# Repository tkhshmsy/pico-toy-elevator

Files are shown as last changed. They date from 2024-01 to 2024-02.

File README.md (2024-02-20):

# pico-toy-elevator

This is a toy that imitates the operation of Elevator.

My son loves Elevators, going up and down for hours, and watching YouTube about it every day.  
I hope he enjoys this...

## Features
* LCD displays floors and operations
* Pressed button is lights up
* Speak according to the movement of the elevator ( in Japanese ! )
* All parts are able to get from [Akizuki Denshi](https://akizukidenshi.com/catalog/default.aspx).
* Use Raspberry Pi Pico with Rust language.

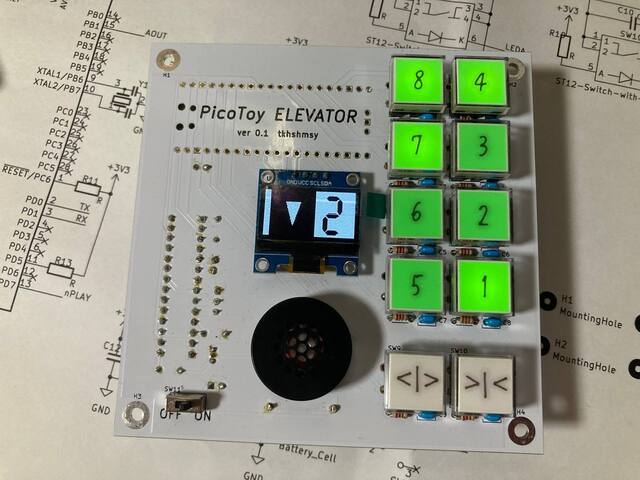
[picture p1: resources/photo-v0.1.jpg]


## Schematic and Layout

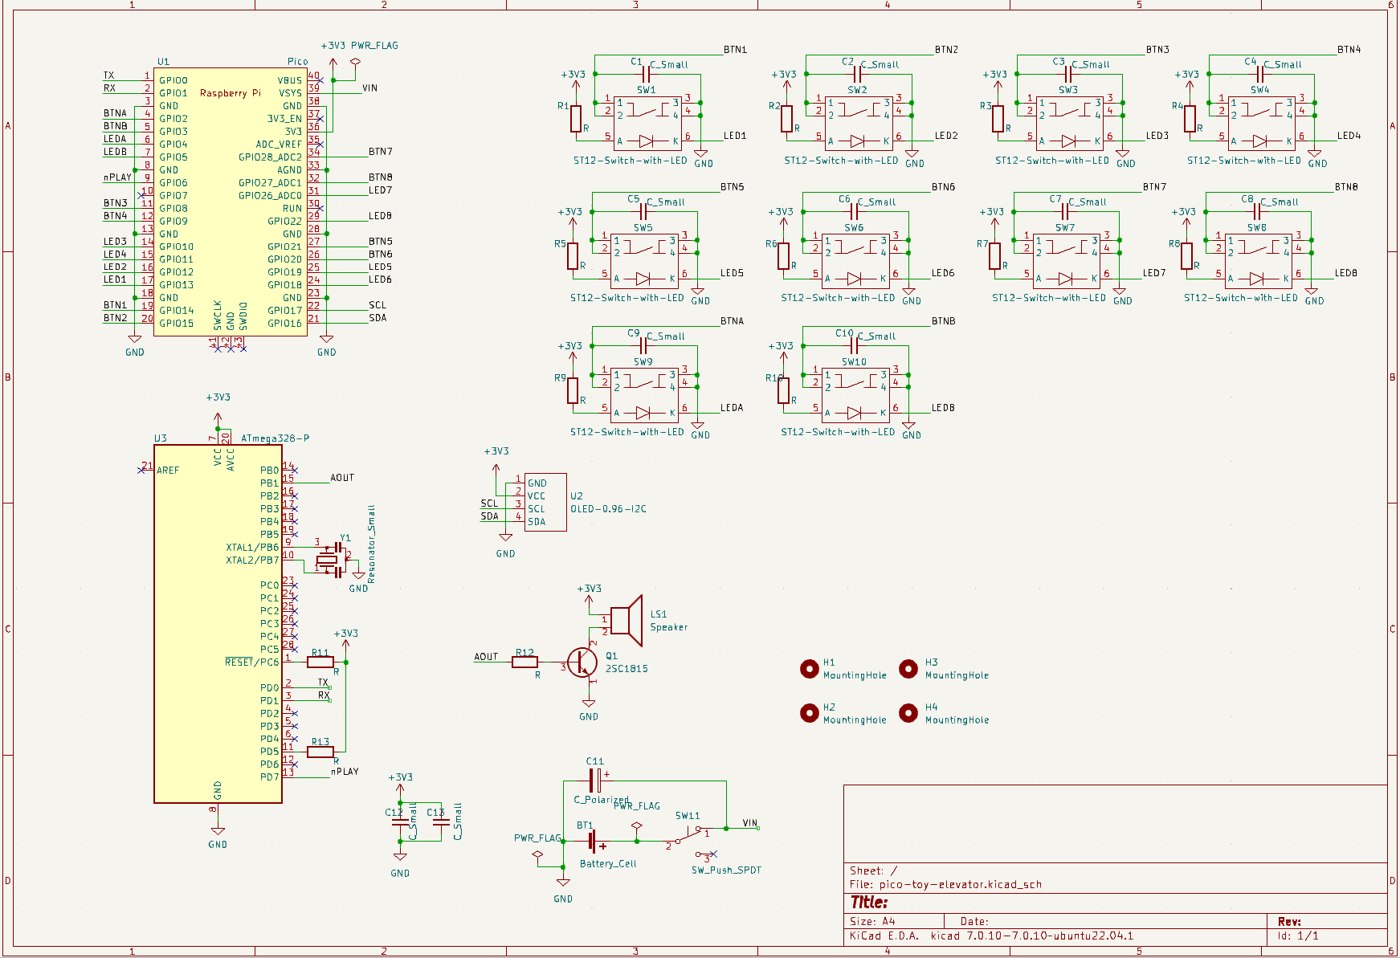
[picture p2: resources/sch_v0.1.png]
schmatic


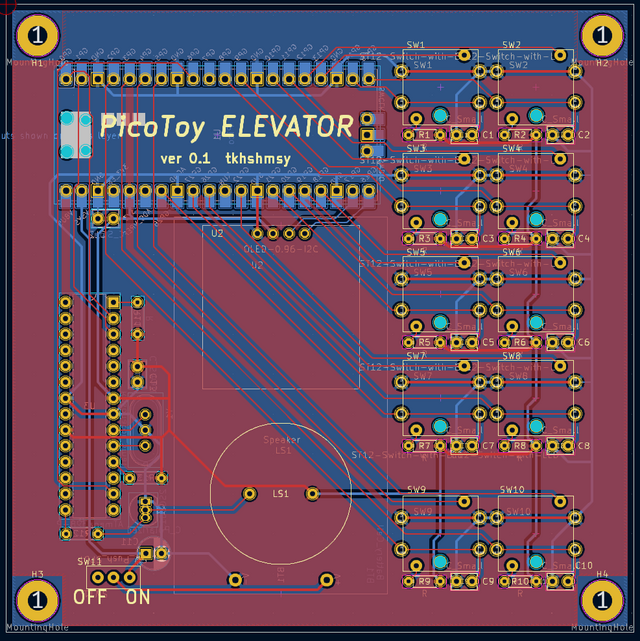
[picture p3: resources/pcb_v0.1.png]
layout


## Bill Of Materials
|Ref|Name|Qty|Description|Link|
|---|----|---|---|----|
|U1|RaspberryPi Pico|1|Micro Controller|[https://akizukidenshi.com/catalog/g/g116132/](https://akizukidenshi.com/catalog/g/g116132/) or [https://akizukidenshi.com/catalog/g/g118085/](https://akizukidenshi.com/catalog/g/g118085/)|
|U2|OLED|1|i2c, 0.96inch|[https://akizukidenshi.com/catalog/g/g112031/](https://akizukidenshi.com/catalog/g/g112031/)|
|U3|Aques Talk Pico|1|ATMega328P|[https://akizukidenshi.com/catalog/g/g109973/](https://akizukidenshi.com/catalog/g/g109973/)|
|BT1|Battery holder|1|2xAAA|[https://akizukidenshi.com/catalog/g/g110197/](https://akizukidenshi.com/catalog/g/g110197/)|
|C1,C2,C3,C4,C5,C6,C7,C8,C9,C10,C12,C13|Capacitor|12|0.1uF|[https://akizukidenshi.com/catalog/g/g115927/](https://akizukidenshi.com/catalog/g/g115927/)|
|C11|Capacitor polar|1|100uF|[https://akizukidenshi.com/catalog/g/g105002/](https://akizukidenshi.com/catalog/g/g105002/)|
|LS1|Speaker|1|8ohm 0.5W|[https://akizukidenshi.com/catalog/g/g109797/](https://akizukidenshi.com/catalog/g/g109797/)|
|Q1|2SC1815|1||[https://akizukidenshi.com/catalog/g/g106475/](https://akizukidenshi.com/catalog/g/g106475/)|
|R1,R2,R3,R4,R5,R6,R7,R8,R9,R10|Resistor 220|10|LED limit||
|R11,R13|Resistor 10K|2|Pull up||
|R12|Resistor 270|1|Speaker drive||
|SW1,SW2,SW3,SW4,SW5,SW6,SW7,SW8,SW9,SW10|Push Switch with LED|10|select any color|Green [https://akizukidenshi.com/catalog/g/g102009/](https://akizukidenshi.com/catalog/g/g102009/) Red [https://akizukidenshi.com/catalog/g/g102010](https://akizukidenshi.com/catalog/g/g102010) Yellow [https://akizukidenshi.com/catalog/g/g115372](https://akizukidenshi.com/catalog/g/g115372)|
|SW11|Slide Switch|1|Power SW|[https://akizukidenshi.com/catalog/g/g115707/](https://akizukidenshi.com/catalog/g/g115707/)|
|Y1|Resonator|1|16MHz|[https://akizukidenshi.com/catalog/g/g109576/](https://akizukidenshi.com/catalog/g/g109576/)|

## License
* MIT

## Author
* tkhshmsy@gmail.com

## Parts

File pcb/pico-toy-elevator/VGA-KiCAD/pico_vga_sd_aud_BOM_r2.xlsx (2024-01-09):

RPI-PVAS pico_vga_sd_aud BOM Rev2
17/079/2020
Reference designators | Quantity | Manufacturer Part Number (MPN) | Manufacturer | Description | Value
C1, C2 | 2 | GCM188R71C105KA64J | Murata | CAP CER 1UF 16V X7R 0603 | 1u
C9, C11 | 2 | GRM188R71A225KE15D | Murata | CAP CER 2.2UF 10V X7R 0603 | 2.2u
C3, C10, C16, C19 | 4 | GRM188R61A106KE69J | Murata | CAP CER 10UF 10V X5R 0603 | 10u
C4, C5, C6, C7, C8, C12, C13 | 7 | GRM155R71E104KE14J | Murata | CAP CER 0.1UF 25V X7R 0402 | 100n
C14, C15, C21 | 3 | GRM219R60J476ME44D | Murata | CAP CER 47UF 6.3V X5R 0805 | 47u
C17, C18 | 2 | GRM155R71H222KA01D | Murata | CAP CER 2200PF 50V X7R 0402 | 2.2n
D1 | 1 | MBR120VLSFT1G | ON Semiconductor | DIODE SCHOTTKY 20V 1A SOD123FL | MBR120VLSFT1G
J1, J2 | 2 | SJ-3523-SMT-TR | CUI Devices | CONN JACK STEREO 3.5MM SMD R/A | SJ-3523-SMT
J3 | 1 | 104031-0811 | Molex | CONN MICRO SD CARD PUSH-PULL R/A | 104031-0811
J4 | 1 | L77HDE15SD1CH4F | Amphenol ICC (Commercial Products) | CONN DSUB HD RCPT 15POS R/A SLDR | L77HDE15SD1CH4F
J5 | 1 | 10103594-0001LF | Amphenol ICC (FCI) | CONN RCPT USB2.0 MICRO B SMD R/A | 10103594-0001LF
J6 | 1 | TSW-102-23-T-S | Samtec Inc. | CONN HEADER VERT 2POS 2.54MM | TSW-102-23-T-S
J7 | 1 | 67997-208HLF | Amphenol ICC (FCI) | CONN HEADER VERT 8POS 2.54MM | 67997-208HLF
R1, R2 | 2 | RC0402FR-07220RL | Yageo | RES SMD 220 OHM 1% 1/16W 0402 | 220
R3, R4 | 2 | RC0402FR-07100RL | Yageo | RES SMD 100 OHM 1% 1/16W 0402 | 100
R5, R6 | 2 | RC0402FR-07470RP | Yageo | RES SMD 470 OHM 1% 1/16W 0402 | 470
R7, R8 | 2 | RC0402FR-071K8L | Yageo | RES SMD 1.8K OHM 1% 1/16W 0402 | 1.8K
R10, R11 | 2 | RC0402FR-0747RL | Yageo | RES SMD 47 OHM 1% 1/16W 0402 | 47
R20, R21, R22, R27, R32, R37 | 6 | RC0402FR-071KP | Yageo | RES SMD 1K OHM 1% 1/16W 0402 | 1k
R23, R24 | 2 | RC0402FR-0710KP | Yageo | RES SMD 10K OHM 1% 1/16W 0402 | 10k
R26, R31, R36 | 3 | RC0402FR-07499RL | Yageo | RES SMD 499 OHM 1% 1/16W 0402 | 499
R28, R33, R38 | 3 | RC0402FR-072KL | Yageo | RES SMD 2K OHM 1% 1/16W 0402 | 2k
R29, R34, R39 | 3 | RC0402FR-074K02L | Yageo | RES SMD 4.02K OHM 1% 1/16W 0402 | 4.02k
R30, R35, R40 | 3 | RC0402FR-078K06L | Yageo | RES SMD 8.06K OHM 1% 1/16W 0402 | 8.06k
SW1, SW2, SW3, SW4 | 4 | 434133025816 | Würth Elektronik | TACT SWITCH 4.2X3.2MM VERTICAL T | 434133025816
U1 | 1 | TLV70033DDCR | Texas Instruments | IC REG LINEAR 3.3V 200MA SOT23-5 | TLV70033DDCR
U3 | 1 | NC7WZ16P6X | ON Semiconductor | IC BUF NON-INVERT 5.5V SC70-6 | NC7WZ16P6X
U4 | 1 | PCM5101APWR | Texas Instruments | IC DAC 16/24/32BIT 384K 20TSSOP | PCM5101APWR

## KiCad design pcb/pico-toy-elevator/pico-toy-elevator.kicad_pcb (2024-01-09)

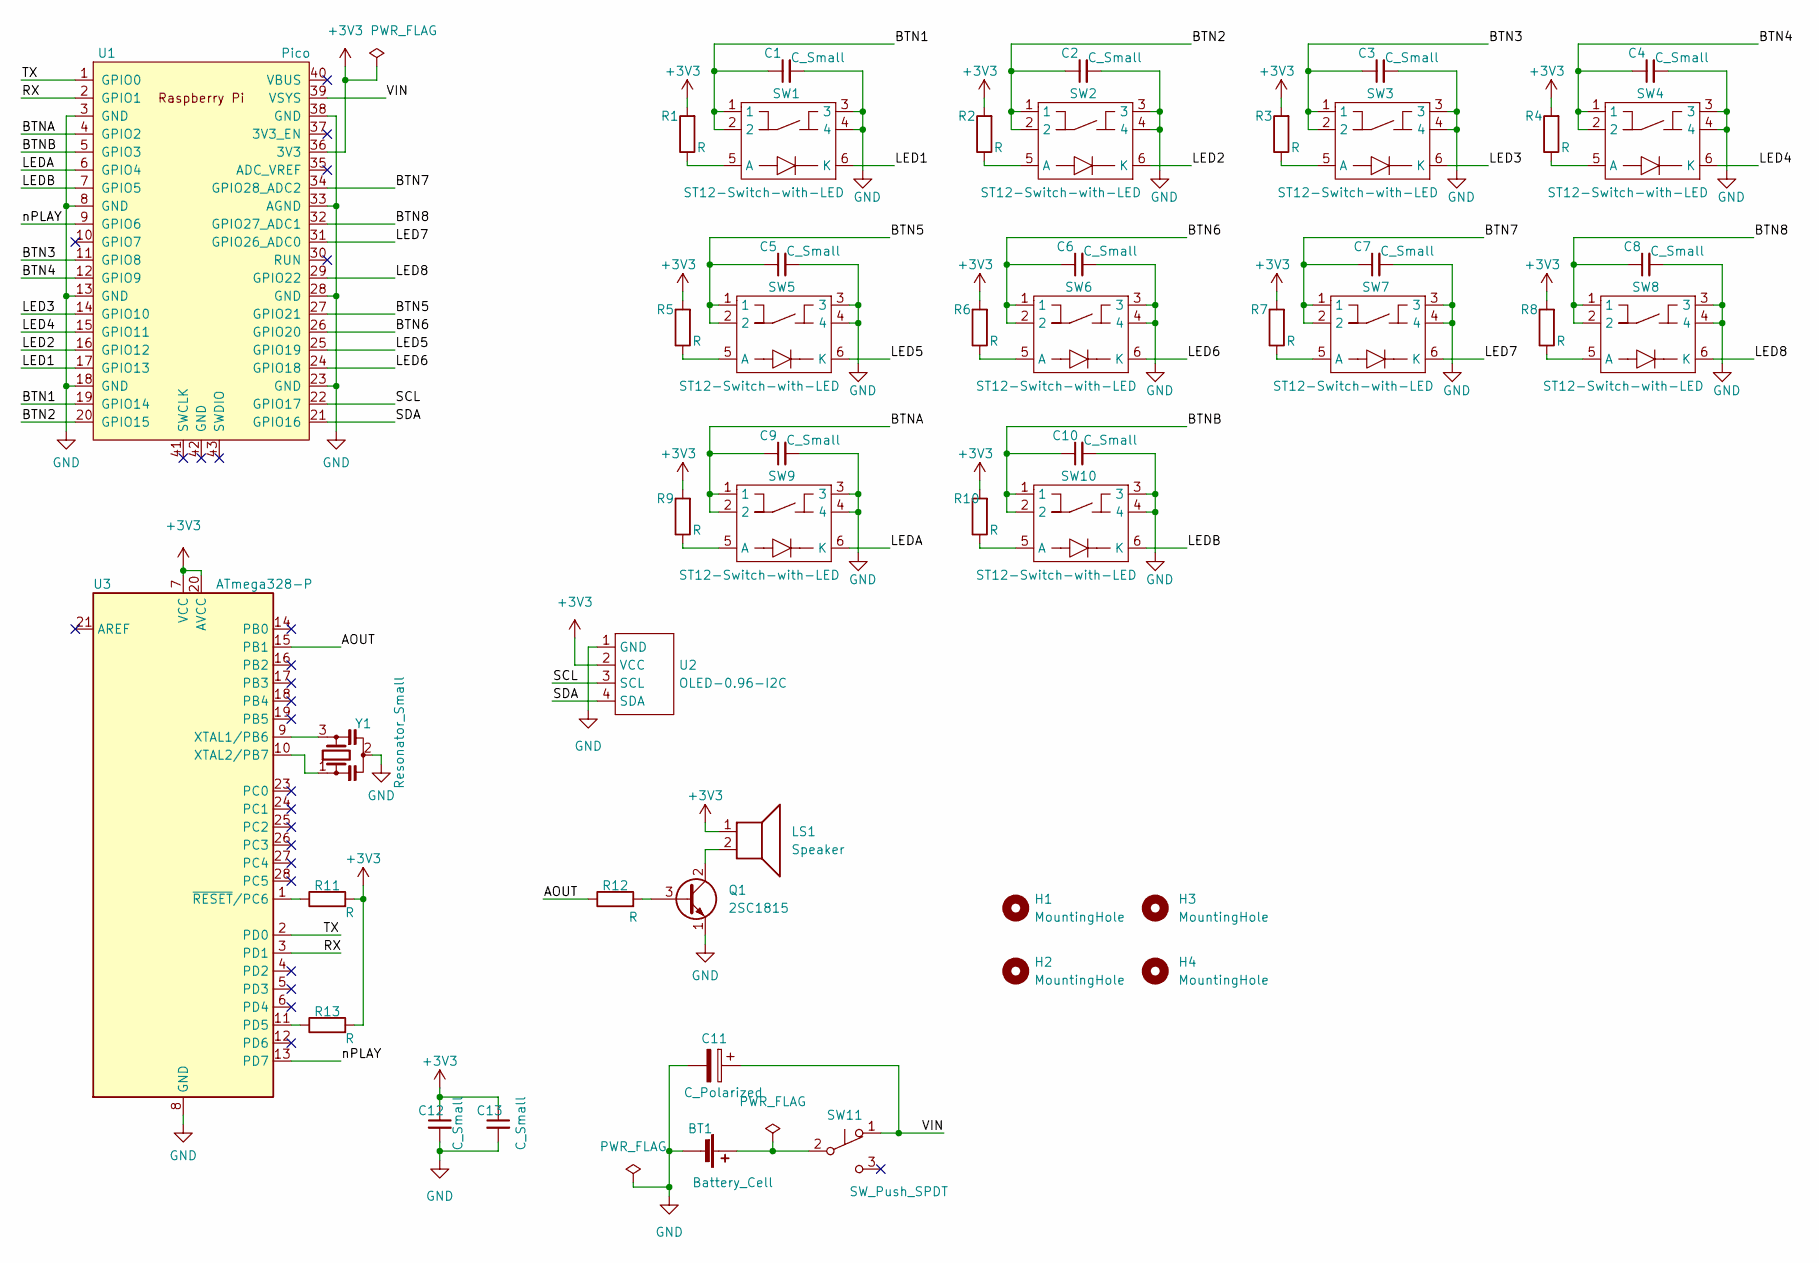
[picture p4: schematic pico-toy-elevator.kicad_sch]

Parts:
BT1: Battery_Cell; BH-321-2P24
C1, C2, C3, C4, C5, C6, C7, C8, C9, C10, C12, C13: C_Small; C_Rect_L4.0mm_W2.5mm_P2.50mm
C11: C_Polarized; CP_Radial_D5.0mm_P2.50mm
H1, H2, H3, H4: MountingHole; MountingHole_3.2mm_M3_Pad
LS1: Speaker; UGSM23A
Q1: 2SC1815; TO-92_Inline
R1, R2, R3, R4, R5, R6, R7, R8, R9, R10, R11, R12, R13: R; R_Axial_DIN0204_L3.6mm_D1.6mm_P5.08mm_Horizontal
SW1, SW2, SW3, SW4, SW5, SW6, SW7, SW8, SW9, SW10: ST12-Switch-with-LED; ST12
SW11: SW_Push_SPDT; SS-12D00G3
U1: Pico; RPi_Pico_SMD_TH
U2: OLED-0.96-I2C
U3: ATmega328-P; DIP-28_W7.62mm
Y1: Resonator_Small; Crystal_HC49-U-3Pin_Vertical

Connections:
+3V3: C12.1, C13.1, LS1.1, R1.2, R2.2, R3.2, R4.2, R5.2, R6.2, R7.2, R8.2, R9.2, R10.2, R11.2, R13.2, U1.36 (3V3), U2.2 (VCC), U3.7 (VCC), U3.20 (AVCC)
/AOUT: R12.1, U3.15 (PB1)
/BTN1: C1.1, SW1.1, SW1.2, U1.19 (GPIO14)
/BTN2: C2.1, SW2.1, SW2.2, U1.20 (GPIO15)
/BTN3: C3.1, SW3.1, SW3.2, U1.11 (GPIO8)
/BTN4: C4.1, SW4.1, SW4.2, U1.12 (GPIO9)
/BTN5: C5.1, SW5.1, SW5.2, U1.27 (GPIO21)
/BTN6: C6.1, SW6.1, SW6.2, U1.26 (GPIO20)
/BTN7: C7.1, SW7.1, SW7.2, U1.34 (GPIO28_ADC2)
/BTN8: C8.1, SW8.1, SW8.2, U1.32 (GPIO27_ADC1)
/BTNA: C9.1, SW9.1, SW9.2, U1.4 (GPIO2)
/BTNB: C10.1, SW10.1, SW10.2, U1.5 (GPIO3)
/LED1: SW1.6 (K), U1.17 (GPIO13)
/LED2: SW2.6 (K), U1.16 (GPIO12)
/LED3: SW3.6 (K), U1.14 (GPIO10)
/LED4: SW4.6 (K), U1.15 (GPIO11)
/LED5: SW5.6 (K), U1.25 (GPIO19)
/LED6: SW6.6 (K), U1.24 (GPIO18)
/LED7: SW7.6 (K), U1.31 (GPIO26_ADC0)
/LED8: SW8.6 (K), U1.29 (GPIO22)
/LEDA: SW9.6 (K), U1.6 (GPIO4)
/LEDB: SW10.6 (K), U1.7 (GPIO5)
/RX: U1.2 (GPIO1), U3.3 (PD1)
/SCL: U1.22 (GPIO17), U2.3 (SCL)
/SDA: U1.21 (GPIO16), U2.4 (SDA)
/TX: U1.1 (GPIO0), U3.2 (PD0)
/VIN: C11.1, SW11.1 (A), U1.39 (VSYS)
/nPLAY: U1.9 (GPIO6), U3.13 (PD7)
GND: BT1.2 (-), C1.2, C2.2, C3.2, C4.2, C5.2, C6.2, C7.2, C8.2, C9.2, C10.2, C11.2, C12.2, C13.2, Q1.1 (E), SW1.3, SW1.4, SW2.3, SW2.4, SW3.3, SW3.4, SW4.3, SW4.4, SW5.3, SW5.4, SW6.3, SW6.4, SW7.3, SW7.4, SW8.3, SW8.4, SW9.3, SW9.4, SW10.3, SW10.4, U1.3 (GND), U1.8 (GND), U1.13 (GND), U1.18 (GND), U1.23 (GND), U1.28 (GND), U1.33 (AGND), U1.38 (GND), U2.1 (GND), U3.8 (GND), U3.22 (GND), Y1.2
unnamed: BT1.1 (+), SW11.2 (B)
unnamed: LS1.2, Q1.2 (C)
unnamed: Q1.3 (B), R12.2
unnamed: R1.1, SW1.5 (A)
unnamed: R2.1, SW2.5 (A)
unnamed: R3.1, SW3.5 (A)
unnamed: R4.1, SW4.5 (A)
unnamed: R5.1, SW5.5 (A)
unnamed: R6.1, SW6.5 (A)
unnamed: R7.1, SW7.5 (A)
unnamed: R8.1, SW8.5 (A)
unnamed: R9.1, SW9.5 (A)
unnamed: R10.1, SW10.5 (A)
unnamed: R11.1, U3.1 (~RESET/PC6)
unnamed: R13.1, U3.11 (PD5)
unnamed: U3.9 (XTAL1/PB6), Y1.3
unnamed: U3.10 (XTAL2/PB7), Y1.1

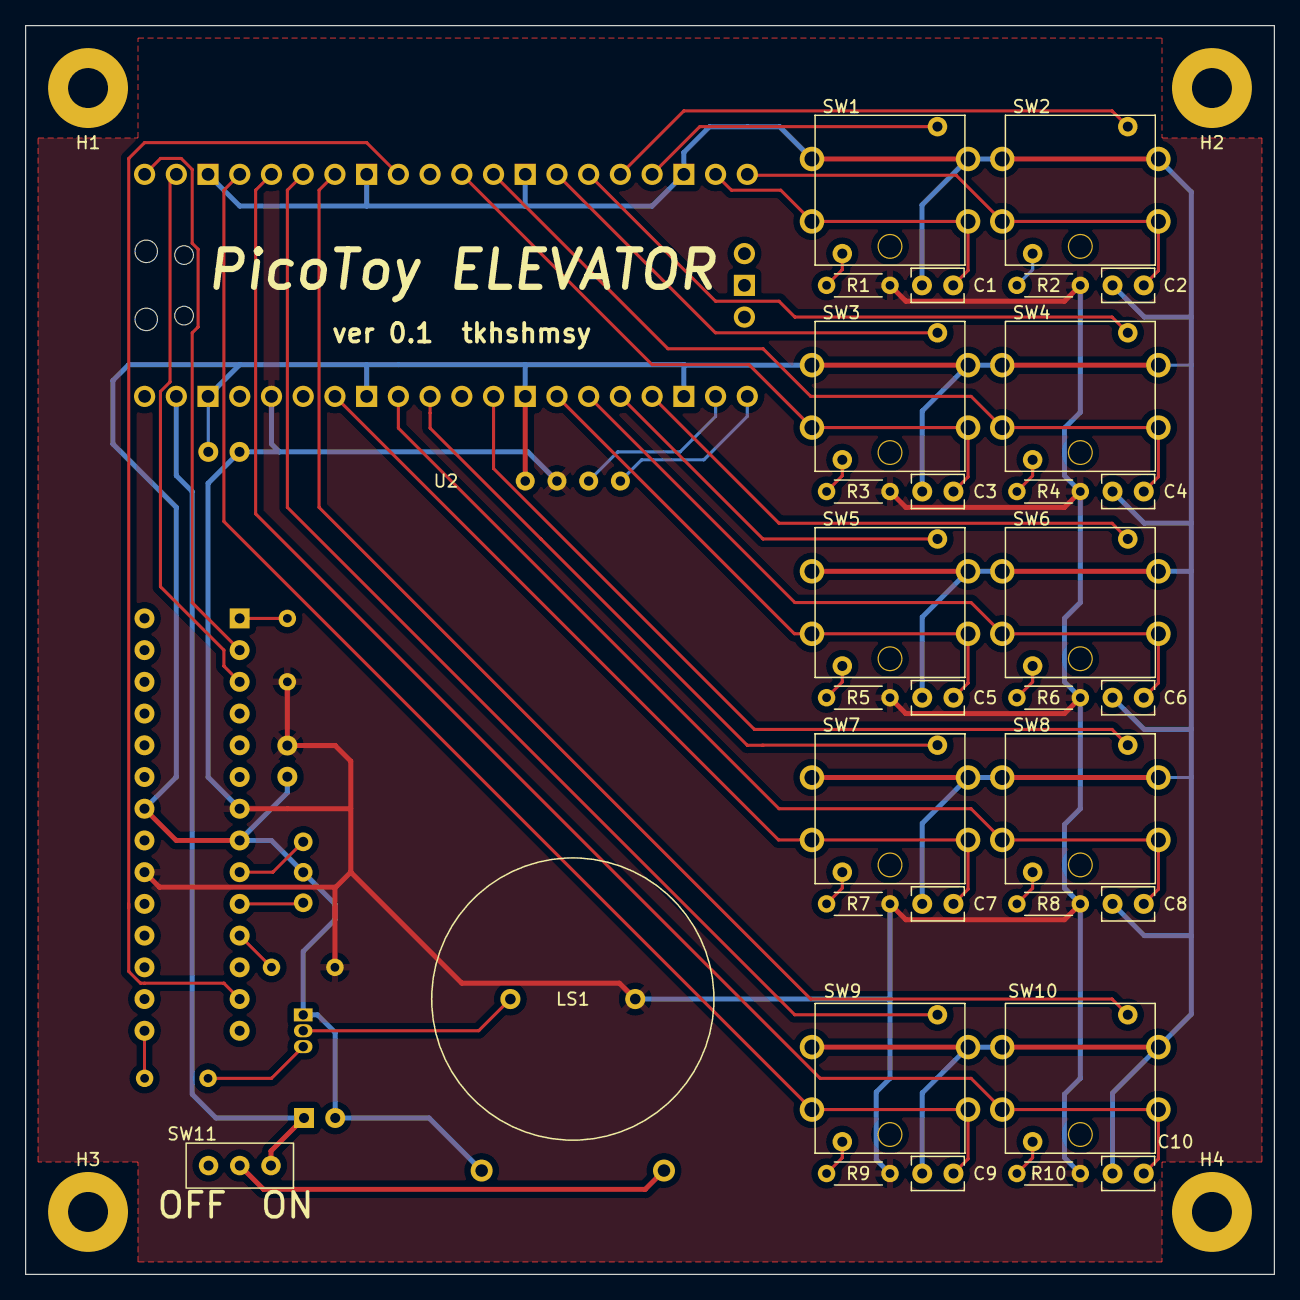
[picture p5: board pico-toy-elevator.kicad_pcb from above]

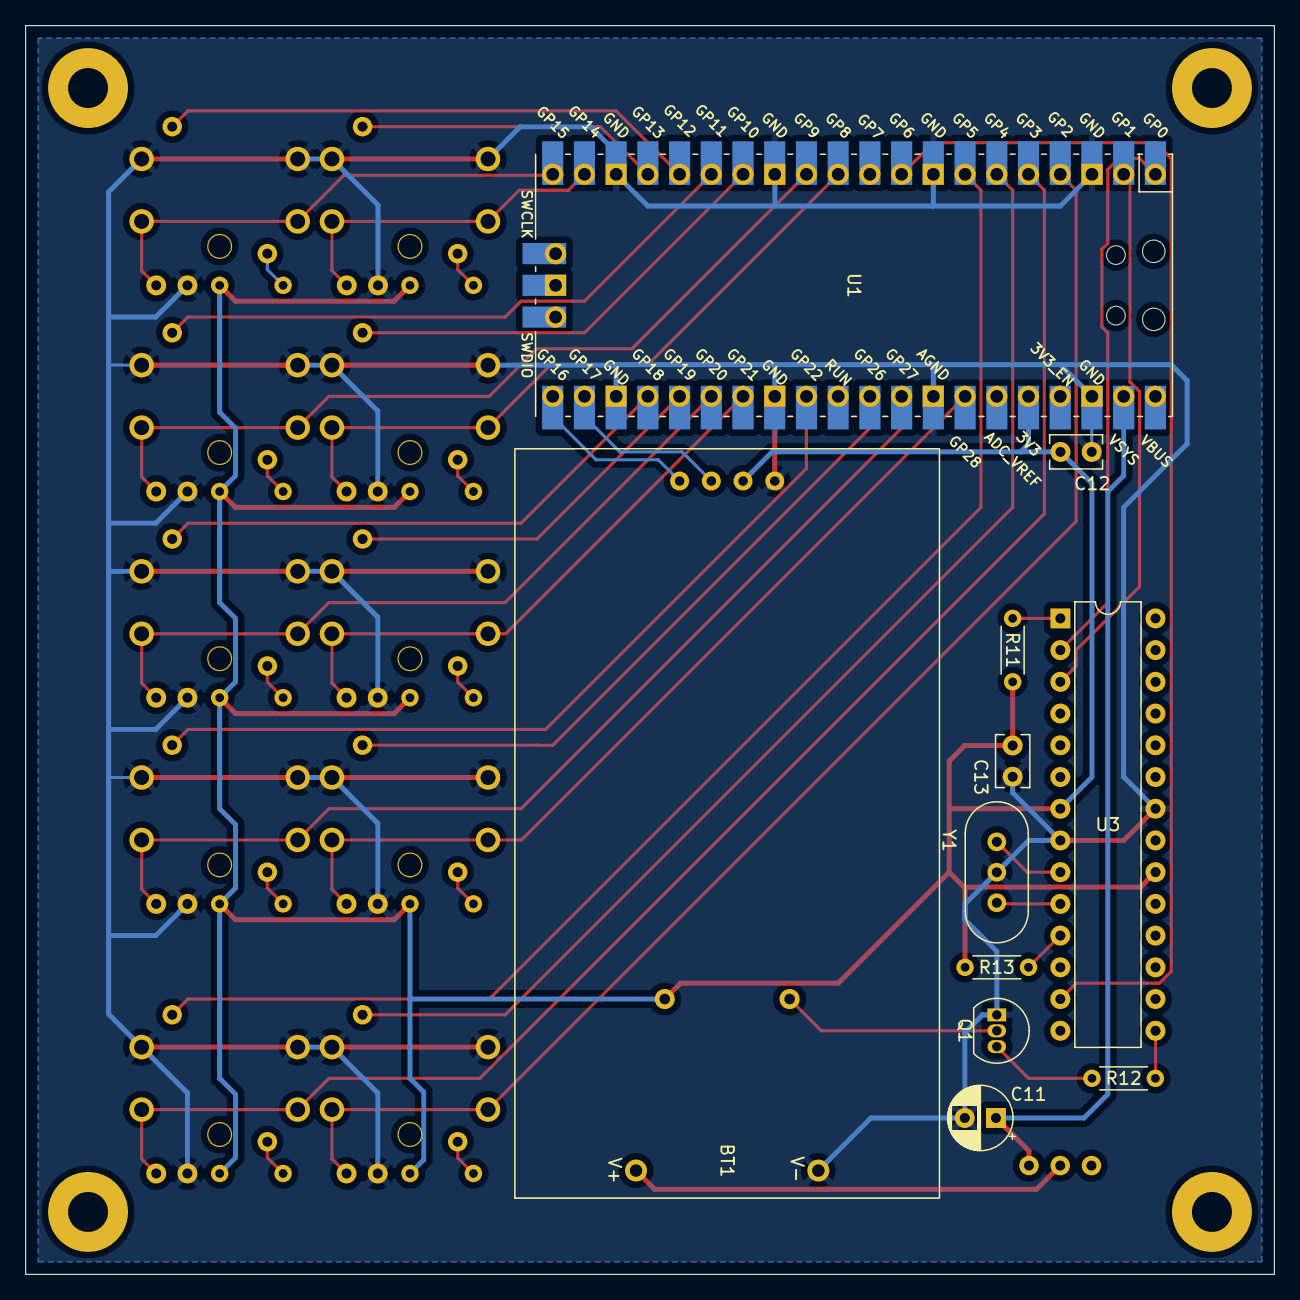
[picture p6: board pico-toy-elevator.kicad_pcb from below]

Board: 2 copper layers, 100.0 x 100.0 mm, 48 parts (11 on the bottom side), 46 nets.

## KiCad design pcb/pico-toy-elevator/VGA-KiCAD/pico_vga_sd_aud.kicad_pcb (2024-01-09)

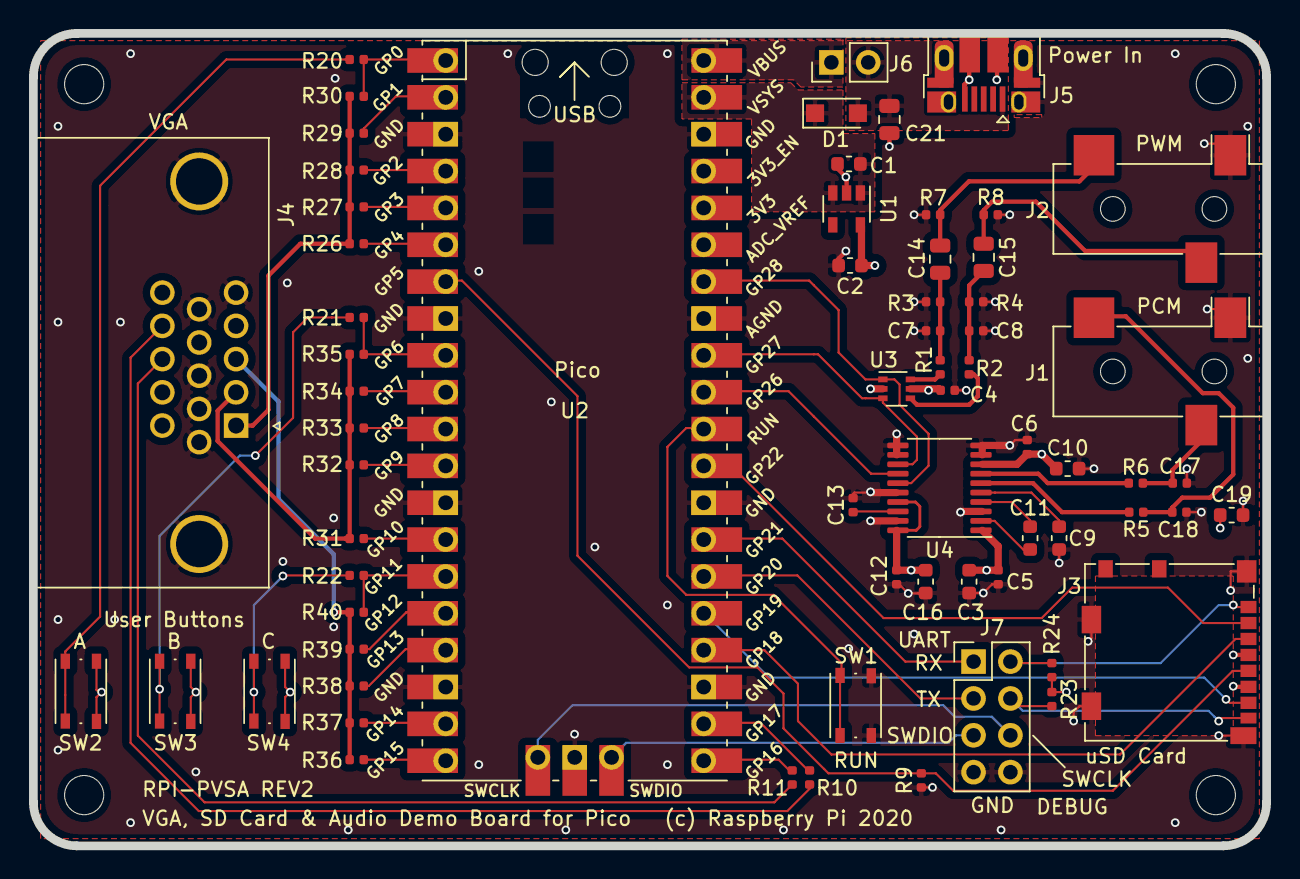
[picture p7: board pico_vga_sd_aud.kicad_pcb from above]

Board: 4 copper layers, 85.0 x 56.0 mm, 71 parts (0 on the bottom side), 59 nets.

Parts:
C1, C2: 1u; C_0603_1608Metric
C3, C10, C16, C19: 10u; C_0603_1608Metric
C4, C5, C6, C7, C8, C12, C13: 100n; C_0402_1005Metric
C9, C11: 2.2u; C_0603_1608Metric
C14, C15, C21: 47u; C_0805_2012Metric
C17, C18: 2.2n; C_0402_1005Metric
D1: MBR120; MBR120_SOD-123
H1, H2, H3, H4: MountingHole; MountingHole_2.7mm_M2.5
J1, J2: AudioJack3; CUI_SJ-3523-audio-jack
J3: Micro_SD_Card; microSD_HC_Molex_104031-0811
J4: L77HDE15SD1CH4F; DSUB-15-L77HDE15SD1CH4F
J5: USB_B_Micro; USB_Micro-B_Amphenol_10103594-0001LF_Horizontal_modified
J6: Conn_01x02; PinHeader_1x02_P2.54mm_Vertical
J7: Conn_02x03_Odd_Even; PinHeader_2x04_P2.54mm_Vertical
R1, R2: 220; R_0402_1005Metric
R3, R4: 100; R_0402_1005Metric
R5, R6: 470; R_0402_1005Metric
R7, R8: 1.8K; R_0402_1005Metric
R9: DNF; R_0402_1005Metric
R10, R11: 47; R_0402_1005Metric
R20, R21, R22, R27, R32, R37: 1k; R_0402_1005Metric
R23, R24: 10k; R_0402_1005Metric
R26, R31, R36: 499; R_0402_1005Metric
R28, R33, R38: 2k; R_0402_1005Metric
R29, R34, R39: 4.02k; R_0402_1005Metric
R30, R35, R40: 8.06k; R_0402_1005Metric
SW1, SW2, SW3, SW4: SW_Push; SW_Push_1P1T_NO_Vertical_Wuerth_434133025816
U1: TLV70033_SOT23-5; SOT-23-5
U2: Pico; RPi_Pico_SMD_TH
U3: NC7WZ16P6X; SOT-363_SC-70-6
U4: PCM5101A; TSSOP-20_4.4x6.5mm_P0.65mm

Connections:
+3.3VA: C2.1, C3.1, C4.1, C5.1, C6.1, C10.1, U1.5, U3.5, U4.1, U4.8
+3V3: C12.1, C16.1, C19.1, J3.4, R23.2, R24.2, SW2.1, SW3.1, SW4.1, U2.36, U4.17, U4.20
+5V: C21.2, D1.2, J5.1, J6.2
/GPIO0: R20.1, R30.2, U2.1
/GPIO1: R29.2, U2.2
/GPIO2: R28.2, U2.4
/GPIO3: R27.2, U2.5
/GPIO4: R26.2, U2.6
/GPIO5: J3.5, R9.2, U2.7
/GPIO6: R21.1, R35.2, U2.9
/GPIO7: R34.2, U2.10
/GPIO8: R33.2, U2.11
/GPIO9: R32.2, U2.12
/GPIO10: R31.2, U2.14
/GPIO11: R22.1, R40.2, U2.15
/GPIO12: R39.2, U2.16
/GPIO13: R38.2, U2.17
/GPIO14: R37.2, U2.19
/GPIO15: R36.2, U2.20
/GPIO16: R11.2, U2.21
/GPIO17: R10.2, U2.22
/GPIO18: J3.3, U2.24
/GPIO19: J3.7, U2.25
/GPIO20: J7.3, U2.26
/GPIO21: J7.1, U2.27
/GPIO22: J3.2, U2.29
/GPIO26: U2.31, U4.14
/GPIO27: U2.32, U3.3, U4.13
/GPIO28: U2.34, U3.1, U4.15
/HSYNC: J4.13, R11.1
/PCM_AUDIO_L: C18.1, J1.2, R5.1
/PCM_AUDIO_R: C17.1, J1.3, R6.1
/PCM_L: R5.2, U4.6
/PCM_R: R6.2, U4.7
/PWM_AUDIO_L: C14.1, J2.2, R7.2
/PWM_AUDIO_R: C15.1, J2.3, R8.2
/PWM_L: R1.2, U3.6
/PWM_LL: C7.1, C14.2, R1.1, R3.2
/PWM_R: R2.2, U3.4
/PWM_RR: C8.1, C15.2, R2.1, R4.2
/RUN: SW1.1, U2.30
/SD_DAT1: J3.8, J7.4, R24.1
/SD_DAT2: J3.1, J7.2, R23.1
/SWCLK: J7.6, U2.41
/SWDIO: J7.5, U2.43
/VGA_B: J4.3, R36.1, R37.1, R38.1, R39.1, R40.1
/VGA_G: J4.2, R31.1, R32.1, R33.1, R34.1, R35.1
/VGA_R: J4.1, R26.1, R27.1, R28.1, R29.1, R30.1
/VSYNC: J4.14, R10.1
/VSYS: C1.1, D1.1, U1.1, U1.3, U2.39
GND: C1.2, C2.2, C3.2, C4.2, C5.2, C6.2, C7.2, C8.2, C9.2, C10.2, C12.2, C13.2, C16.2, C17.2, C18.2, C19.2, C21.1, J1.1, J2.1, J3.6, J3.11, J4.0, J4.5, J4.6, J4.7, J4.8, J4.10, J5.5, J5.6, J7.7, J7.8, R3.1, R4.1, R7.1, R8.1, R9.1, SW1.2, U1.2, U2.3, U2.8, U2.13, U2.18, U2.23, U2.28, U2.33, U2.38, U2.42, U3.2, U4.3, U4.9, U4.10, U4.11, U4.12, U4.16, U4.19
unnamed: C9.1, U4.5
unnamed: C11.1, U4.2
unnamed: C11.2, U4.4
unnamed: C13.1, U4.18
unnamed: R20.2, SW2.2
unnamed: R21.2, SW3.2
unnamed: R22.2, SW4.2
VBUS: J6.1, U2.40

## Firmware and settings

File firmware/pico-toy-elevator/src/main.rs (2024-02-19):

// =======================
//  pico-toy-elevator
//
//  by tkhshmsy@gmail.com
// =======================

#![no_std]
#![no_main]

use bsp::entry;
// use defmt::*;
use defmt_rtt as _;
use embedded_hal::digital::v2::{InputPin, OutputPin, PinState, ToggleableOutputPin};
use panic_probe as _;

use rp_pico as bsp;

use bsp::hal::{
    clocks::{init_clocks_and_plls, Clock},
    fugit::RateExtU32,
    pac,
    sio::Sio,
    uart::{DataBits, StopBits, UartConfig},
    watchdog::Watchdog,
};

use embedded_graphics::{
    pixelcolor::BinaryColor,
    prelude::*,
    primitives::{PrimitiveStyle, Rectangle, Triangle},
    text::{Baseline, Text},
};
use font_7seg::Font7Seg;
use shared_bus::BusManagerSimple;
use ssd1306::{prelude::*, Ssd1306};

pub mod lift;
use lift::{Directions, FloorState, LiftState};
pub mod voice;

static OFFSET_X: i32 = 8;

#[entry]
fn main() -> ! {
    let mut pac = pac::Peripherals::take().unwrap();
    let core = pac::CorePeripherals::take().unwrap();
    let mut watchdog = Watchdog::new(pac.WATCHDOG);
    let sio = Sio::new(pac.SIO);

    // External high-speed crystal on the pico board is 12Mhz
    let external_xtal_freq_hz = 12_000_000u32;
    let clocks = init_clocks_and_plls(
        external_xtal_freq_hz,
        pac.XOSC,
        pac.CLOCKS,
        pac.PLL_SYS,
        pac.PLL_USB,
        &mut pac.RESETS,
        &mut watchdog,
    )
    .ok()
    .unwrap();

    let mut delay = cortex_m::delay::Delay::new(core.SYST, clocks.system_clock.freq().to_Hz());

    let pins = bsp::Pins::new(
        pac.IO_BANK0,
        pac.PADS_BANK0,
        sio.gpio_bank0,
        &mut pac.RESETS,
    );

    let mut led_pin = pins.led.into_push_pull_output();

    // GPIO
    let btn_a = pins.gpio2.into_pull_up_input();
    let btn_b = pins.gpio3.into_pull_up_input();
    let mut led_a = pins.gpio4.into_push_pull_output();
    let mut led_b = pins.gpio5.into_push_pull_output();
    let nplay = pins.gpio6.into_pull_up_input();
    //gpio7 is unused
    let btn_3 = pins.gpio8.into_pull_up_input();
    let btn_4 = pins.gpio9.into_pull_up_input();
    let mut led_3 = pins.gpio10.into_push_pull_output();
    let mut led_4 = pins.gpio11.into_push_pull_output();
    let mut led_2 = pins.gpio12.into_push_pull_output();
    let mut led_1 = pins.gpio13.into_push_pull_output();
    let btn_1 = pins.gpio14.into_pull_up_input();
    let btn_2 = pins.gpio15.into_pull_up_input();
    let mut led_6 = pins.gpio18.into_push_pull_output();
    let mut led_5 = pins.gpio19.into_push_pull_output();
    let btn_6 = pins.gpio20.into_pull_up_input();
    let btn_5 = pins.gpio21.into_pull_up_input();
    let mut led_8 = pins.gpio22.into_push_pull_output();
    let mut led_7 = pins.gpio26.into_push_pull_output();
    let btn_8 = pins.gpio27.into_pull_up_input();
    let btn_7 = pins.gpio28.into_pull_up_input();

    // wait for booting up i2c devices
    delay.delay_ms(1000);

    // UART0
    let uart_pins = (pins.gpio0.into_function(), pins.gpio1.into_function());
    let uart0 = bsp::hal::uart::UartPeripheral::new(pac.UART0, uart_pins, &mut pac.RESETS)
        .enable(
            UartConfig::new(9600.Hz(), DataBits::Eight, None, StopBits::One),
            clocks.peripheral_clock.freq(),
        )
        .unwrap();

    // I2C0
    // let i2c_pins = (pins.gpio16.into_function(), pins.gpio17.into_function());
    let sda_pin = pins.gpio16.into_function();
    let scl_pin = pins.gpio17.into_function();
    let i2c = bsp::hal::I2C::i2c0(
        pac.I2C0,
        sda_pin,
        scl_pin,
        400.kHz(),
        &mut pac.RESETS,
        &clocks.peripheral_clock,
    );
    let i2c_bus = BusManagerSimple::new(i2c);
    let ssd1306_proxy = i2c_bus.acquire_i2c();

    delay.delay_ms(1000);
    let ssd1306_interface = ssd1306::I2CDisplayInterface::new(ssd1306_proxy);
    let mut display = Ssd1306::new(
        ssd1306_interface,
        DisplaySize128x64,
        DisplayRotation::Rotate0,
    )
    .into_buffered_graphics_mode();
    display.init().unwrap();
    let line_style = PrimitiveStyle::with_stroke(BinaryColor::Off, 5);
    let fill_style = PrimitiveStyle::with_fill(BinaryColor::Off);
    let erase_style = PrimitiveStyle::with_fill(BinaryColor::On);
    let font7seg_style = Font7Seg::new(Size::new(30, 60), BinaryColor::Off);
    display.clear();
    display.flush().unwrap();

    // ===========
    //  main loop
    // ===========
    let mut lift = lift::Lift::new();
    let mut voice = voice::Voice::new(uart0).unwrap();

    let mut heartbeat_counter = 0;
    let mut animation_counter = 0;
    let mut prev_floor = FloorState::FloorMax;

    voice.talk("#K\r");
    delay.delay_ms(1000);
    voice.talk("#J\r");
    delay.delay_ms(1000);

    loop {
        delay.delay_ms(33);

        //heart beat
        heartbeat_counter += 1;
        if heartbeat_counter % 15 == 0 {
            led_pin.toggle().unwrap();
        }

        // key input
        {
            if btn_1.is_low().unwrap() {
                lift.set_floor_key(FloorState::Floor8th, true);
            }
            if btn_2.is_low().unwrap() {
                lift.set_floor_key(FloorState::Floor4th, true);
            }
            if btn_3.is_low().unwrap() {
                lift.set_floor_key(FloorState::Floor7th, true);
            }
            if btn_4.is_low().unwrap() {
                lift.set_floor_key(FloorState::Floor3rd, true);
            }
            if btn_5.is_low().unwrap() {
                lift.set_floor_key(FloorState::Floor6th, true);
            }
            if btn_6.is_low().unwrap() {
                lift.set_floor_key(FloorState::Floor2nd, true);
            }
            if btn_7.is_low().unwrap() {
                lift.set_floor_key(FloorState::Floor5th, true);
            }
            if btn_8.is_low().unwrap() {
                lift.set_floor_key(FloorState::Floor1st, true);
            }
            if btn_a.is_low().unwrap() {
                led_a.set_low().unwrap();
                lift.open();
            } else {
                led_a.set_high().unwrap();
            }
            if btn_b.is_low().unwrap() {
                led_b.set_low().unwrap();
                lift.close();
            } else {
                led_b.set_high().unwrap();
            }
        }

        // control floor led
        {
            let keys = lift.keys();
            led_1
                .set_state(PinState::from(!keys[FloorState::Floor8th as usize]))
                .unwrap();
            led_2
                .set_state(PinState::from(!keys[FloorState::Floor4th as usize]))
                .unwrap();
            led_3
                .set_state(PinState::from(!keys[FloorState::Floor7th as usize]))
                .unwrap();
            led_4
                .set_state(PinState::from(!keys[FloorState::Floor3rd as usize]))
                .unwrap();
            led_5
                .set_state(PinState::from(!keys[FloorState::Floor6th as usize]))
                .unwrap();
            led_6
                .set_state(PinState::from(!keys[FloorState::Floor2nd as usize]))
                .unwrap();
            led_7
                .set_state(PinState::from(!keys[FloorState::Floor5th as usize]))
                .unwrap();
            led_8
                .set_state(PinState::from(!keys[FloorState::Floor1st as usize]))
                .unwrap();
        }

        // display floor
        if prev_floor != *lift.floor_state() {
            Rectangle::new(
                Point::new(OFFSET_X + 64, 0),
                Size::new(128 - OFFSET_X as u32, 64),
            )
            .into_styled(erase_style)
            .draw(&mut display)
            .unwrap();
            let mut c = "0";
            match lift.floor_state() {
                FloorState::Floor1st => c = "1",
                FloorState::Floor2nd => c = "2",
                FloorState::Floor3rd => c = "3",
                FloorState::Floor4th => c = "4",
                FloorState::Floor5th => c = "5",
                FloorState::Floor6th => c = "6",
                FloorState::Floor7th => c = "7",
                FloorState::Floor8th => c = "8",
                FloorState::FloorMax => {}
            }
            Text::with_baseline(c, Point::new(64 + 16, 4), font7seg_style, Baseline::Top)
                .draw(&mut display)
                .unwrap();
            display.flush().unwrap();
        }

        // animation
        Rectangle::new(Point::new(0, 0), Size::new(64 + OFFSET_X as u32, 64))
            .into_styled(erase_style)
            .draw(&mut display)
            .unwrap();
        if animation_counter >= 0 {
            match lift.lift_state() {
                LiftState::Opening => {
                    let counter = animation_counter;
                    match counter {
                        65..=100 => {
                            // skip erase because already done
                            if (counter % 10) > 5 {
                                Triangle::new(
                                    Point::new(OFFSET_X + 32 - 10, 14),
                                    Point::new(OFFSET_X + 10, 32),
                                    Point::new(OFFSET_X + 32 - 10, 50),
                                )
                                .into_styled(fill_style)
                                .draw(&mut display)
                                .unwrap();
                                Triangle::new(
                                    Point::new(OFFSET_X + 32 + 10, 14),
                                    Point::new(OFFSET_X + 64 - 10, 32),
                                    Point::new(OFFSET_X + 32 + 10, 50),
                                )
                                .into_styled(fill_style)
                                .draw(&mut display)
                                .unwrap();
                            }
                        }
                        0..=64 => {
                            let dx = (counter / 2) as i32;
                            let width = (dx * 2) as u32;
                            Rectangle::new(Point::new(OFFSET_X + dx, 0), Size::new(64 - width, 64))
                                .into_styled(fill_style)
                                .draw(&mut display)
                                .unwrap();
                        }
                        _ => {}
                    }
                }
                LiftState::Waiting => {
                    Rectangle::new(Point::new(OFFSET_X + 0, 0), Size::new(64, 64))
                        .into_styled(fill_style)
                        .draw(&mut display)
                        .unwrap();
                    match lift.direction() {
                        Directions::Up => Triangle::new(
                            Point::new(OFFSET_X + 32, 16),
                            Point::new(OFFSET_X + 32 - 10, 48),
                            Point::new(OFFSET_X + 32 + 10, 48),
                        )
                        .into_styled(erase_style)
                        .draw(&mut display)
                        .unwrap(),
                        Directions::Down => Triangle::new(
                            Point::new(OFFSET_X + 32, 48),
                            Point::new(OFFSET_X + 32 - 10, 16),
                            Point::new(OFFSET_X + 32 + 10, 16),
                        )
                        .into_styled(erase_style)
                        .draw(&mut display)
                        .unwrap(),
                        Directions::None => {}
                    };
                }
                LiftState::Closing => {
                    let counter = animation_counter;
                    match counter {
                        65..=100 => {
                            Rectangle::new(Point::new(OFFSET_X + 0, 0), Size::new(64, 64))
                                .into_styled(fill_style)
                                .draw(&mut display)
                                .unwrap();
                            if (counter % 10) > 5 {
                                Triangle::new(
                                    Point::new(OFFSET_X + 10, 14),
                                    Point::new(OFFSET_X + 32 - 10, 32),
                                    Point::new(OFFSET_X + 10, 50),
                                )
                                .into_styled(erase_style)
                                .draw(&mut display)
                                .unwrap();
                                Triangle::new(
                                    Point::new(OFFSET_X + 64 - 10, 14),
                                    Point::new(OFFSET_X + 32 + 10, 32),
                                    Point::new(OFFSET_X + 64 - 10, 50),
                                )
                                .into_styled(erase_style)
                                .draw(&mut display)
                                .unwrap();
                            }
                        }
                        0..=64 => {
                            let dx = (counter / 2) as i32;
                            let width = (dx * 2) as u32;
                            Rectangle::new(Point::new(OFFSET_X + 32 - dx, 0), Size::new(width, 64))
                                .into_styled(fill_style)
                                .draw(&mut display)
                                .unwrap();
                        }
                        _ => {}
                    }
                }
                LiftState::Moving => {
                    let steps = [0, 5, 10, 15, 20, -20, -15, -10, -5, 0];
                    let diff = steps[(animation_counter % 10) as usize];
                    match lift.direction() {
                        Directions::Up => {
                            Triangle::new(
                                Point::new(OFFSET_X + 32, 8),
                                Point::new(OFFSET_X + 32 - diff, 56),
                                Point::new(OFFSET_X + 32 + diff, 56),
                            )
                            .into_styled(line_style)
                            .draw(&mut display)
                            .unwrap();
                        }
                        Directions::Down => {
                            Triangle::new(
                                Point::new(OFFSET_X + 32, 56),
                                Point::new(OFFSET_X + 32 - diff, 8),
                                Point::new(OFFSET_X + 32 + diff, 8),
                            )
                            .into_styled(line_style)
                            .draw(&mut display)
                            .unwrap();
                        }
                        Directions::None => {}
                    };
                }
                _ => {}
            }
            animation_counter -= 1;
        }

        display.flush().unwrap();
        prev_floor = lift.floor_state().clone();
        if nplay.is_low().unwrap() || animation_counter > 0 {
            continue;
        }

        // next state and floor
        let prev_lift_state = lift.lift_state().clone();
        lift.next();

        // talk
        if prev_lift_state != *lift.lift_state() || prev_floor != *lift.floor_state() {
            match lift.lift_state() {
                LiftState::Chime => {
                    match lift.direction() {
                        Directions::Up => voice.talk("#J\r"),
                        Directions::Down => voice.talk("#K\r"),
                        Directions::None => {}
                    };
                }
                LiftState::Arrived => {
                    match lift.floor_state() {
                        FloorState::Floor1st => {
                            voice.talk("<NUMK VAL=1 COUNTER=kai>de'_su.\r");
                        }
                        FloorState::Floor2nd => {
                            voice.talk("<NUMK VAL=2 COUNTER=kai>de'_su.\r");
                        }
                        FloorState::Floor3rd => {
                            voice.talk("<NUMK VAL=3 COUNTER=kai>de'_su.\r");
                        }
                        FloorState::Floor4th => {
                            voice.talk("<NUMK VAL=4 COUNTER=kai>de'_su.\r");
                        }
                        FloorState::Floor5th => {
                            voice.talk("<NUMK VAL=5 COUNTER=kai>de'_su.\r");
                        }
                        FloorState::Floor6th => {
                            voice.talk("<NUMK VAL=6 COUNTER=kai>de'_su.\r");
                        }
                        FloorState::Floor7th => {
                            voice.talk("<NUMK VAL=7 COUNTER=kai>de'_su.\r");
                        }
                        FloorState::Floor8th => {
                            voice.talk("<NUMK VAL=8 COUNTER=kai>de'_su.\r");
                        }
                        FloorState::FloorMax => {
                            voice.talk("kokowa/do'ko?\r");
                        }
                    };
                    animation_counter = 60;
                }
                LiftState::Opening => {
                    voice.talk("do'aga/hirakima'_su.\r");
                    animation_counter = 100;
                }
                LiftState::Waiting => {
                    match lift.direction() {
                        Directions::Up => voice.talk("ue'ni/mairima'_su.\r"),
                        Directions::Down => voice.talk("_shitani/mairima'_su.\r"),
                        Directions::None => {}
                    };
                    animation_counter = 60;
                }
                LiftState::Closing => {
                    voice.talk("do'aga/shimarima'_su.\r");
                    animation_counter = 100;
                }
                LiftState::Checking => voice.talk("i_kisakibo'tanno/o_shitekudasa'i.\r"),
                LiftState::Checked => {}
                LiftState::Moving => {
                    animation_counter = 60;
                }
            }
        }
    }
}

// End of file

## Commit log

2024-01-09 Initial Commit with PCB v 0.1
    [pico-toy-elevator-B_Cu.gbl, pico-toy-elevator-B_Mask.gbs, pico-toy-elevator-B_Silkscreen.gbo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]
2024-01-21 fix PCB
